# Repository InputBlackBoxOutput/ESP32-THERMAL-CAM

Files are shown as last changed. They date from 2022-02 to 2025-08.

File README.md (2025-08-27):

# ESP32 THERMAL CAM

## Assembly
- Enclosure consists of two parts and is held together using self-tapping screws 
- The PCB is attached to the enclosure using self-tapping screws driven into mounting bosses

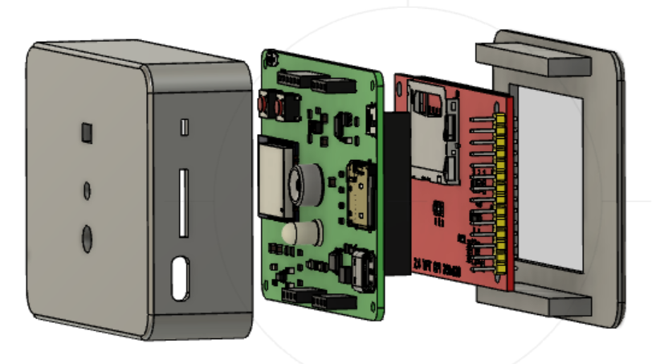
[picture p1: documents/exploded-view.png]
assembly


## Hardware block diagram
- ESP32-WROOM: Control the functionality of the entire design
- LEDs: Indicate the status of the thermal camera
- Pushbutton: Indicate the camera to save the image
- TFT Display: Display thermal images captured by the camera
- SD Card: Store thermal image captured by the camera
- TOF Proximity Sensor: Calculate the proximity of the camera with the surface in front of it
- IR Thermal Sensor Array: Capture IR emissions and create a thermal image of the surface
- LiPo Battery + BMS: Provide power to the camera thereby making it portable

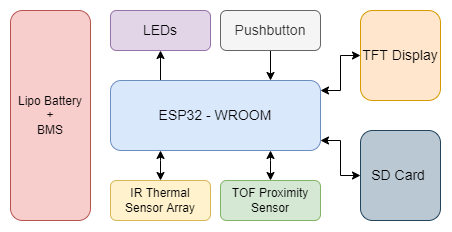
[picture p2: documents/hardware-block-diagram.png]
Hardware block diagram


## Application
- Connect with the thermal camera
- Display thermal image with an appropriate legend 
- Capture and save the thermal image 

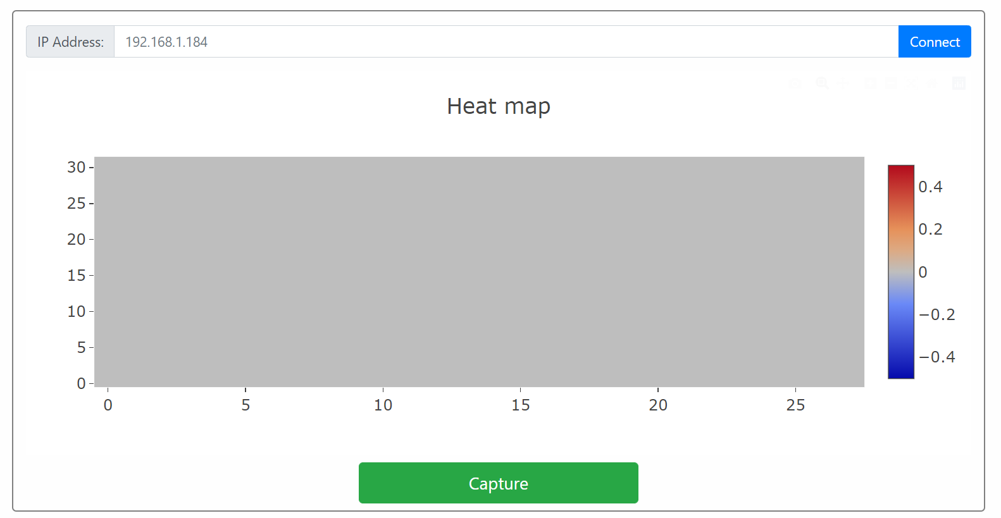
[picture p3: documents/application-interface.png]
Application interface


### Made with lots of ⏱️, 📚 and ☕ by InputBlackBoxOutput

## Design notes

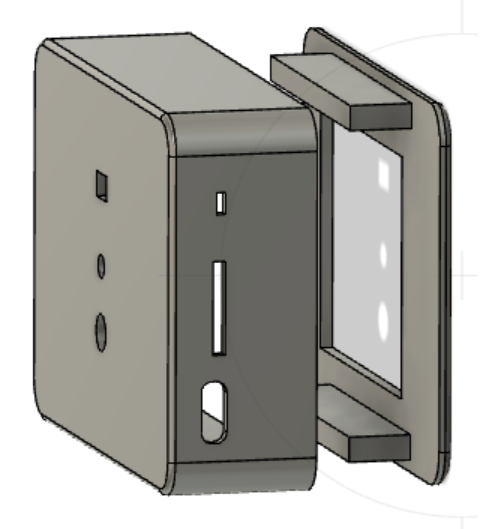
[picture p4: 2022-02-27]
enclosure/enclosure.png

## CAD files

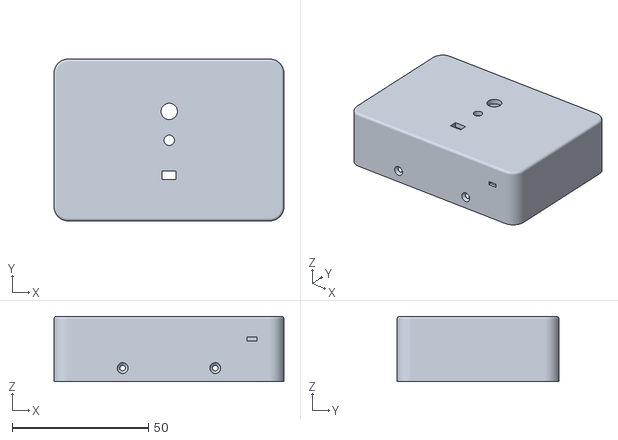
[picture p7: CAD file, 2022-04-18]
enclosure/Enclosure-Front.stl
84.4 x 59.4 x 24.0

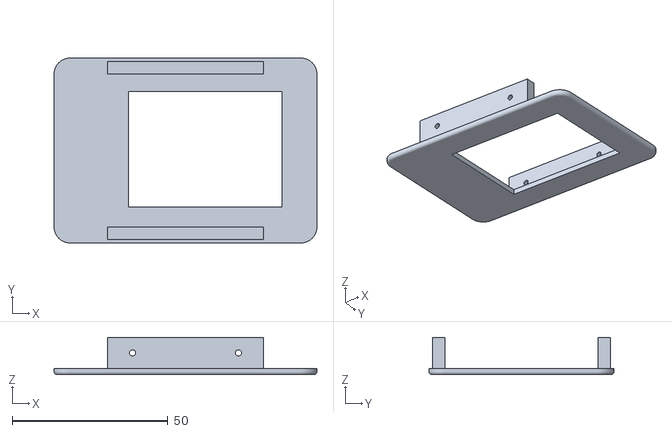
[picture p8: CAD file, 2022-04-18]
enclosure/Enclosure-Back-With-Display-Cutout.stl
84.4 x 59.4 x 12.0

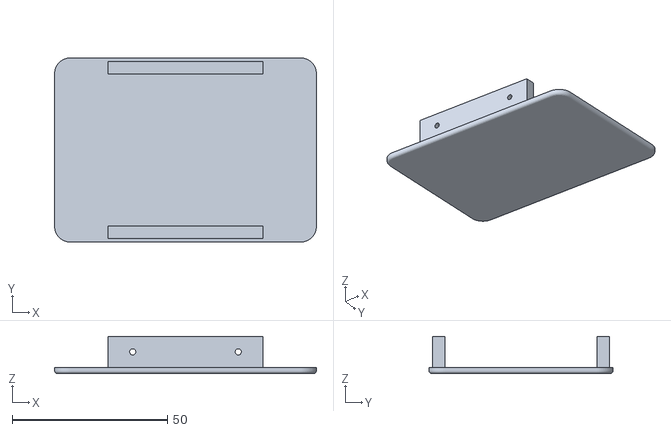
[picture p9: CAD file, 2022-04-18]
enclosure/Enclosure-Back-Without-Display-Cutout.stl
84.4 x 59.4 x 12.0

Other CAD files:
enclosure/Enclosure-Back-With-Display-Cutout.f3d
enclosure/Enclosure-Back-Without-Display-Cutout.f3d
enclosure/Enclosure-Front.f3d

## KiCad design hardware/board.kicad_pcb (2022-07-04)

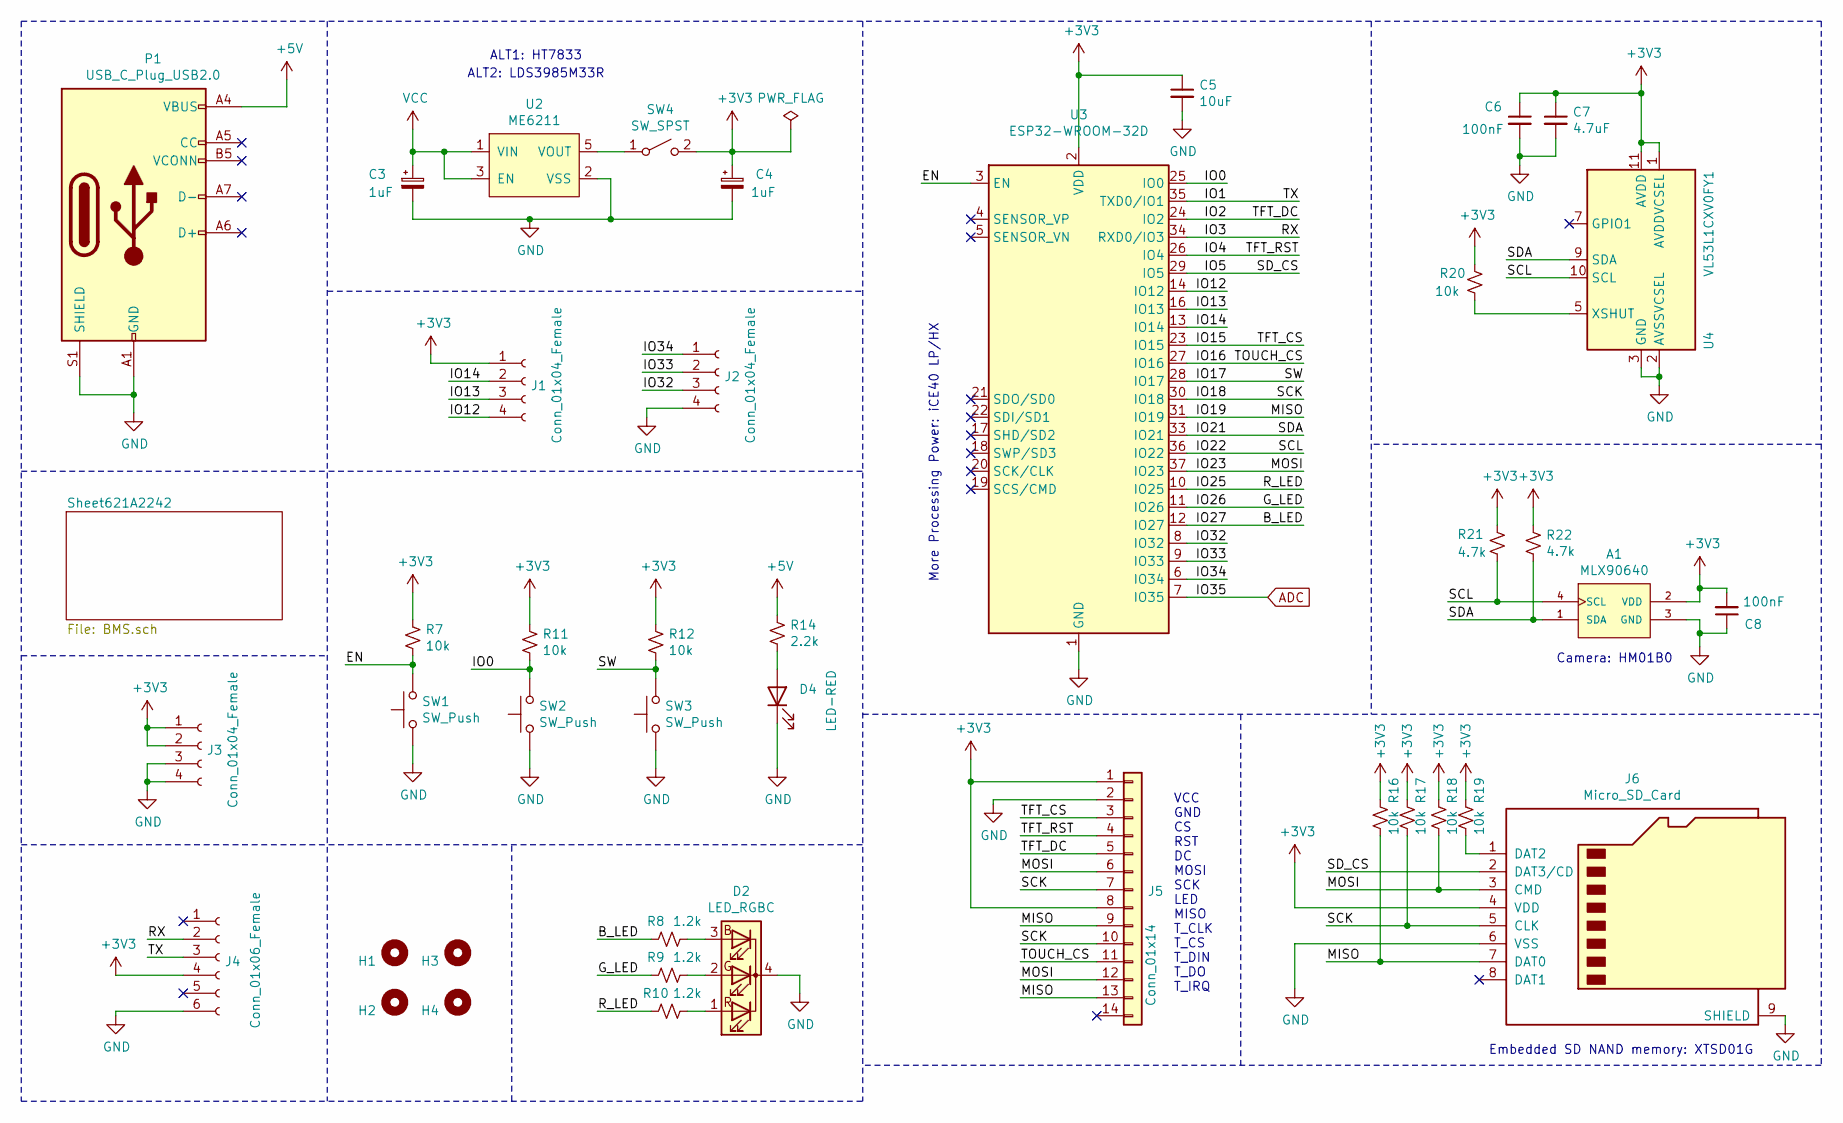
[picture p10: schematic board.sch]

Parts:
A1: MLX90640; TO292P930H600-4; PARTREV 11
C3, C4: 1uF; C_0805_2012Metric_Pad1.18x1.45mm_HandSolder
C5: 10uF; C_0805_2012Metric_Pad1.18x1.45mm_HandSolder
C6, C8: 100nF; C_0805_2012Metric_Pad1.18x1.45mm_HandSolder
C7: 4.7uF; C_0805_2012Metric_Pad1.18x1.45mm_HandSolder
D2: LED_RGBC; LED_D5.0mm-4_RGB
D4: LED-RED; LED_0805_2012Metric_Pad1.15x1.40mm_HandSolder
H1, H2, H3, H4: MountingHole; MountingHole_2.2mm_M2
J1, J2, J3: Conn_01x04_Female; PinSocket_1x04_P2.54mm_Vertical
J4: Conn_01x06_Female; PinSocket_1x06_P2.54mm_Vertical
J5: Conn_01x14; PinSocket_1x14_P2.54mm_Vertical_SMD_Pin1Left
J6: Micro_SD_Card; GCT-MEM2055-00-190-01-A
P1: USB_C_Plug_USB2.0; USB_C_Receptacle_HRO_TYPE-C-31-M-12
R7, R11, R12, R16, R17, R18, R19, R20: 10k; R_0805_2012Metric_Pad1.20x1.40mm_HandSolder
R8, R9, R10: 1.2k; R_0805_2012Metric_Pad1.20x1.40mm_HandSolder
R14: 2.2k; R_0805_2012Metric_Pad1.20x1.40mm_HandSolder
R21, R22: 4.7k; R_0805_2012Metric_Pad1.20x1.40mm_HandSolder
SW1, SW2: SW_Push; SW_SPST_Omron_B3FS-100xP
SW3: SW_Push; SW_SPST_EVQP7A
SW4: SW_SPST; SW_SPDT_PCM12
U2: ME6211; SOT-23-5_HandSoldering
U3: ESP32-WROOM-32D; ESP32-WROOM-32
U4: VL53L1CXV0FY1; ST_VL53L1x

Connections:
+3V3: A1.2 (VDD), C4.1, C5.1, C6.1, C7.1, C8.2, J1.1, J3.1, J3.2, J4.4, J5.1, J5.8, J6.4 (VDD), R7.1, R11.1, R12.1, R16.1, R17.1, R18.1, R19.1, R20.1, R21.1, R22.1, SW4.2 (B), U3.2 (VDD), U4.1 (AVDDVCSEL), U4.11 (AVDD)
+5V: P1.A4 (VBUS), P1.A9 (VBUS), P1.B4 (VBUS), P1.B9 (VBUS), R14.1; also elsewhere on the board
/B_LED: R8.2, U3.12 (IO27)
/EN: R7.2, SW1.2, U3.3 (EN)
/G_LED: R9.2, U3.11 (IO26)
/IO0: R11.2, SW2.2, U3.25 (IO0)
/IO1: J4.3, U3.35 (TXD0/IO1)
/IO2: J5.5, U3.24 (IO2)
/IO3: J4.2, U3.34 (RXD0/IO3)
/IO4: J5.4, U3.26 (IO4)
/IO5: J6.2 (DAT3/CD), U3.29 (IO5)
/IO12: J1.4, U3.14 (IO12)
/IO13: J1.3, U3.16 (IO13)
/IO14: J1.2, U3.13 (IO14)
/IO15: J5.3, U3.23 (IO15)
/IO16: J5.11, U3.27 (IO16)
/IO17: R12.2, SW3.2, U3.28 (IO17)
/IO18: J5.7, J5.10, J6.5 (CLK), R17.2, U3.30 (IO18)
/IO19: J5.9, J5.13, J6.7 (DAT0), R16.2, U3.31 (IO19)
/IO21: A1.1 (SDA), R22.2, U3.33 (IO21), U4.9 (SDA)
/IO22: A1.4 (SCL), R21.2, U3.36 (IO22), U4.10 (SCL)
/IO23: J5.6, J5.12, J6.3 (CMD), R18.2, U3.37 (IO23)
/IO25: R10.2, U3.10 (IO25)
/IO32: J2.3, U3.8 (IO32)
/IO33: J2.2, U3.9 (IO33)
/IO34: J2.1, U3.6 (IO34)
ADC: U3.7 (IO35); also elsewhere on the board
GND: A1.3 (GND), C3.2, C4.2, C5.2, C6.2, C7.2, C8.1, D2.4 (K), D4.1 (K), J2.4, J3.3, J3.4, J4.6, J5.2, J6.6 (VSS), J6.9 (SHIELD), P1.A1 (GND), P1.A12 (GND), P1.B1 (GND), P1.B12 (GND), P1.S1 (SHIELD), SW1.1, SW2.1, SW3.1, U2.2 (VSS), U3.1 (GND), U3.15 (GND), U3.38 (GND), U3.39 (GND), U4.2 (AVSSVCSEL), U4.3 (GND), U4.4 (GND), U4.6 (GND), U4.12 (GND); also elsewhere on the board
unnamed: D2.1 (RA), R10.1
unnamed: D2.2 (GA), R9.1
unnamed: D2.3 (BA), R8.1
unnamed: D4.2 (A), R14.2
unnamed: J6.1 (DAT2), R19.2
unnamed: R20.2, U4.5 (XSHUT)
unnamed: SW4.1 (A), U2.5 (VOUT)
VCC: C3.1, U2.1 (VIN), U2.3 (EN); also elsewhere on the board

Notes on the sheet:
Camera: HM01B0
More Processing Power: iCE40 LP/HX
VCC GND CS RST DC MOSI SCK LED MISO T_CLK T_CS T_DIN T_DO T_IRQ
Embedded SD NAND memory: XTSD01G
ALT1: HT7833
ALT2: LDS3985M33R

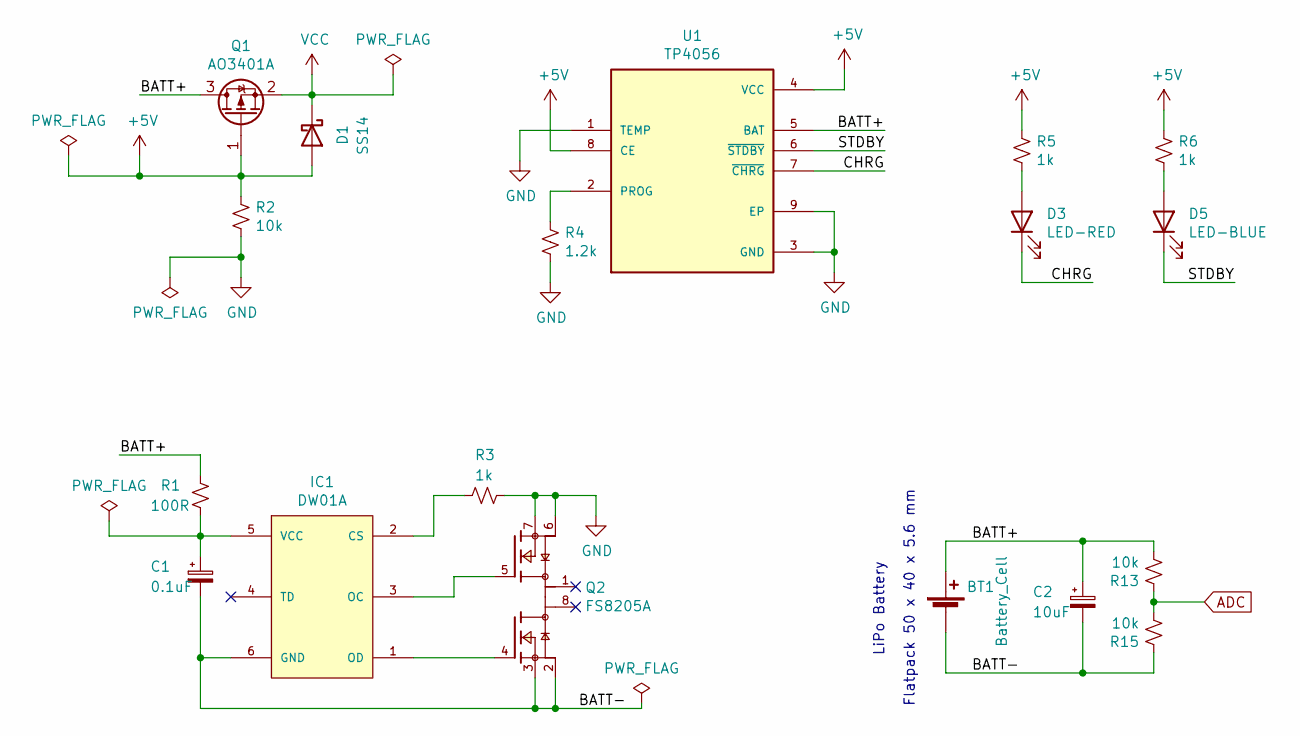
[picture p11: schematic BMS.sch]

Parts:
BT1: Battery_Cell; SolderWire-01x02-SMD-BATT
C1: 0.1uF; C_0805_2012Metric_Pad1.18x1.45mm_HandSolder
C2: 10uF; C_0805_2012Metric_Pad1.18x1.45mm_HandSolder
D1: SS14; D_SMB
D3: LED-RED; LED_0805_2012Metric_Pad1.15x1.40mm_HandSolder
D5: LED-BLUE; LED_0805_2012Metric_Pad1.15x1.40mm_HandSolder
IC1: DW01A; SOT-23-6_Handsoldering; MPN DW01A; LCSC C351410
Q1: AO3401A; SOT-23
Q2: FS8205A; SOP65P640X120-8N; PARTREV 1.7
R1: 100R; R_0805_2012Metric_Pad1.20x1.40mm_HandSolder
R2, R13, R15: 10k; R_0805_2012Metric_Pad1.20x1.40mm_HandSolder
R3, R5, R6: 1k; R_0805_2012Metric_Pad1.20x1.40mm_HandSolder
R4: 1.2k; R_0805_2012Metric_Pad1.20x1.40mm_HandSolder
U1: TP4056; SOP127P600X175-9N

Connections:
+5V: D1.2 (A), Q1.1 (G), R2.1, R5.1, R6.1, U1.4 (VCC), U1.8 (CE); also elsewhere on the board
/Sheet621A2242/BATT+: BT1.1 (+), C2.1, Q1.3 (D), R1.1, R13.2, U1.5 (BAT)
/Sheet621A2242/BATT-: BT1.2 (-), C1.2, C2.2, IC1.6 (GND), Q2.2, Q2.3, R15.1
/Sheet621A2242/CHRG: D3.1 (K), U1.7 (~CHRG)
/Sheet621A2242/STDBY: D5.1 (K), U1.6 (~STDBY)
ADC: R13.1, R15.2; also elsewhere on the board
GND: Q2.6, Q2.7, R2.2, R3.1, R4.2, U1.1 (TEMP), U1.3 (GND), U1.9 (EP); also elsewhere on the board
unnamed: C1.1, IC1.5 (VCC), R1.2
unnamed: D3.2 (A), R5.2
unnamed: D5.2 (A), R6.2
unnamed: IC1.1 (OD), Q2.4
unnamed: IC1.2 (CS), R3.2
unnamed: IC1.3 (OC), Q2.5
unnamed: R4.1, U1.2 (PROG)
VCC: D1.1 (K), Q1.2 (S); also elsewhere on the board

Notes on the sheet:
LiPo Battery
Flatpack 50 x 40 x 5.6 mm

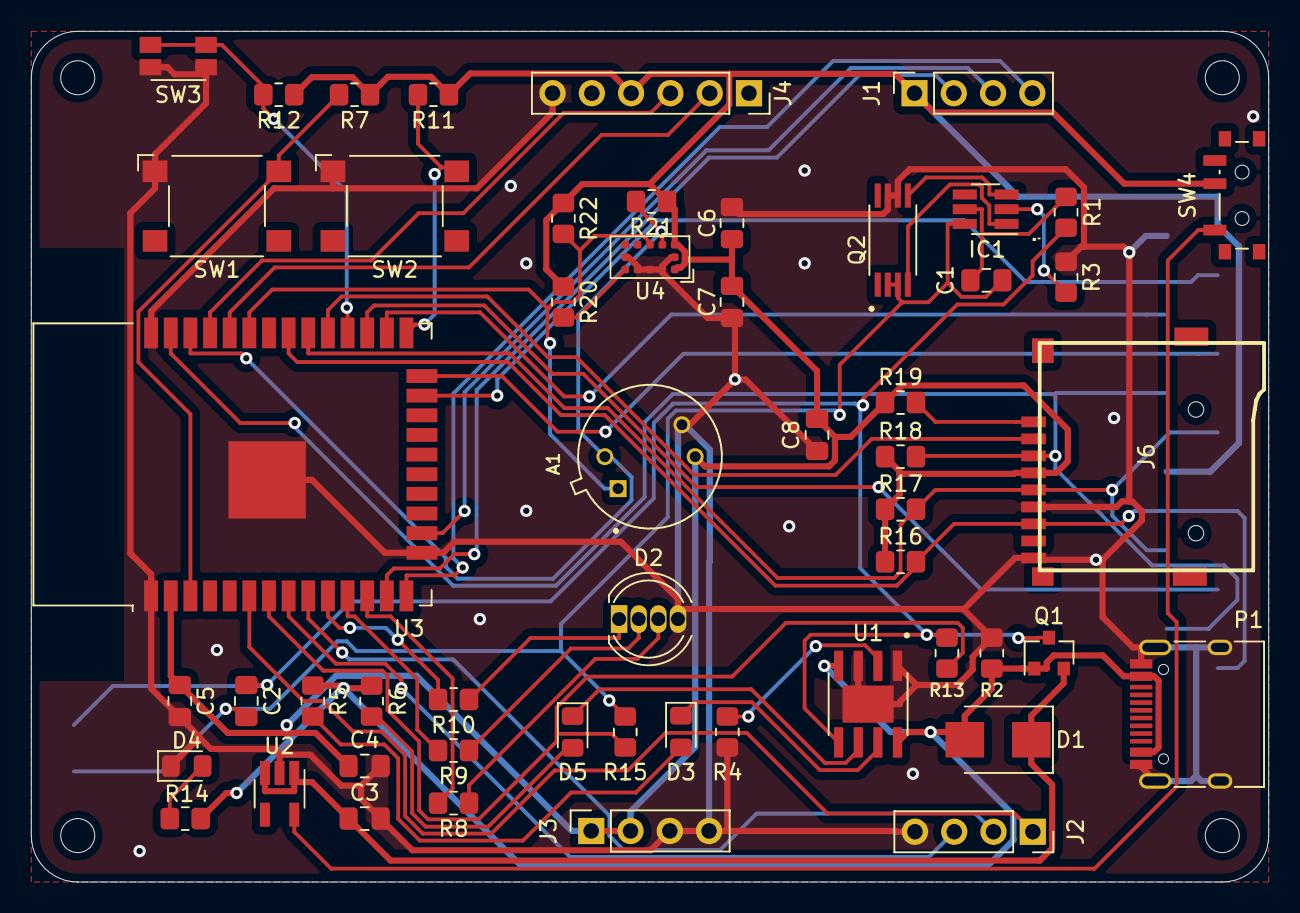
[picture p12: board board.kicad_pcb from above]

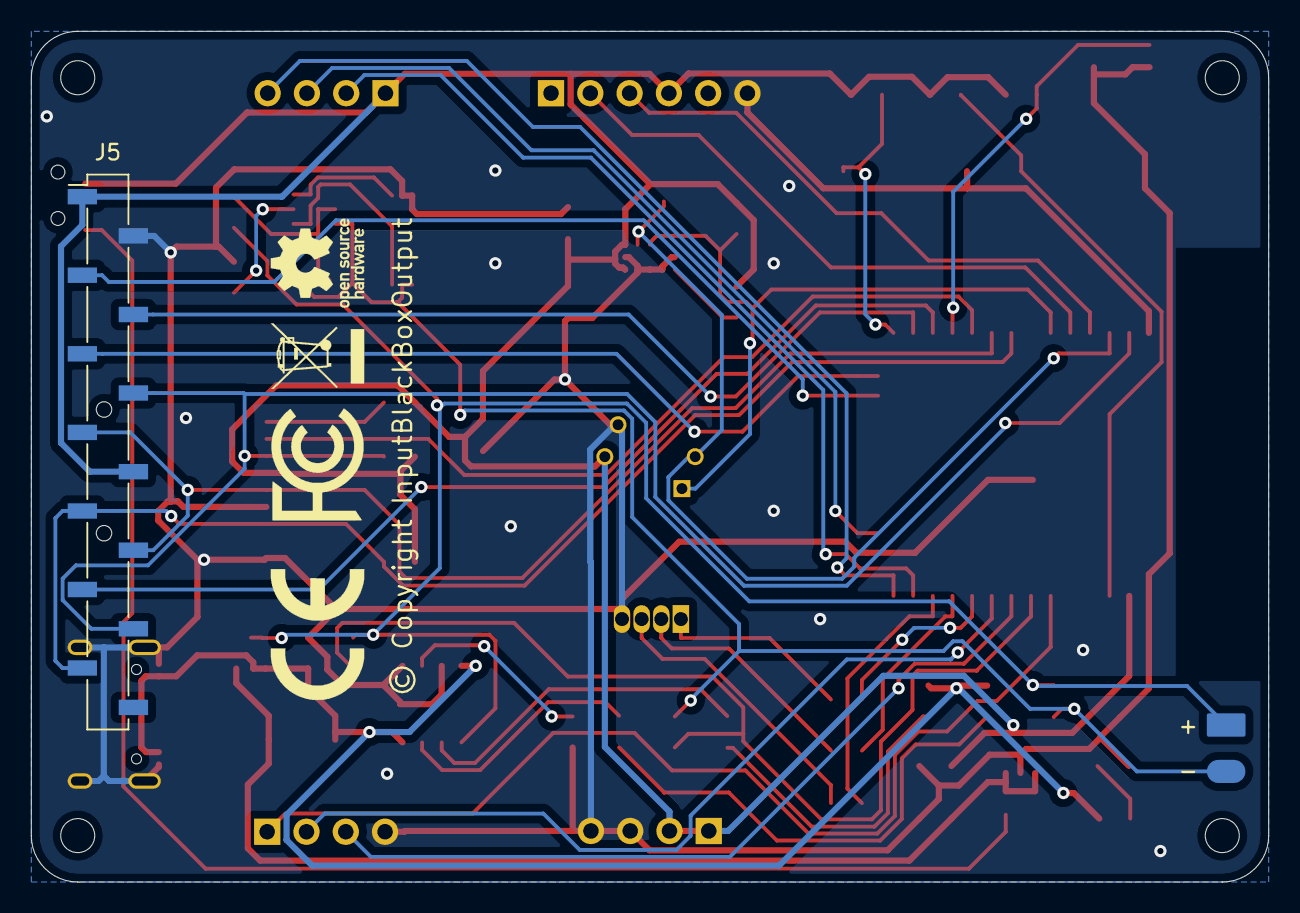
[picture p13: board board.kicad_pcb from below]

Board: 2 copper layers, 80.0 x 55.0 mm, 59 parts (2 on the bottom side), 47 nets.

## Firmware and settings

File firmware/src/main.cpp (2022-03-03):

#include <Arduino.h>
#define LOOP_DELAY 200 // ms

#include "MLX90640.h"
#include "server.h"

MLX90640 mlx;
ESP32Server server;

void setup()
{
  Serial.begin(115200);
  Serial.println("Serial port connected!");

  mlx.setup();
  server.setup();
}

void loop()
{
  mlx.readTempValues();
  server.handleClient(mlx.timestamp, mlx.tempValues);

  delay(LOOP_DELAY);
}

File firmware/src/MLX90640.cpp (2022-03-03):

#include "MLX90640.h"

void MLX90640::setup()
{
    // Connect with MLX90640 via I2C
    Wire.begin();
    Wire.setClock(400000);
    Wire.beginTransmission((uint8_t)MLX90640_address);
    if (Wire.endTransmission() != 0)
        Serial.println("MLX90640 not detected at default I2C address. Please check wiring.");
    else
        Serial.println("MLX90640 initialized!");

    // Get MLX90640 device parameters
    int status;
    uint16_t eeMLX90640[832];

    status = MLX90640_DumpEE(MLX90640_address, eeMLX90640);
    if (status != 0)
        Serial.println("Failed to load system parameters");

    status = MLX90640_ExtractParameters(eeMLX90640, &mlx90640);
    if (status != 0)
        Serial.println("Parameter extraction failed");

    MLX90640_SetRefreshRate(MLX90640_address, 0x05); // 8Hz
    Wire.setClock(800000);
}

// Read pixel data from MLX90640.
void MLX90640::readTempValues()
{
    timestamp = millis();
    for (byte x = 0; x < 2; x++) // Read both subpages
    {
        uint16_t mlx90640Frame[834];
        int status = MLX90640_GetFrameData(MLX90640_address, mlx90640Frame);
        if (status < 0)
        {
            Serial.print("GetFrame Error: ");
            Serial.println(status);
        }

        // float vdd = MLX90640_GetVdd(mlx90640Frame, &mlx90640);
        float Ta = MLX90640_GetTa(mlx90640Frame, &mlx90640);

        float tr = Ta - ta_shift; // Reflected temperature based on the sensor ambient temperature

        MLX90640_CalculateTo(mlx90640Frame, &mlx90640, emmisivity, tr, tempValues);
    }
}

void MLX90640::printTempValues()
{
    Serial.print("Timestamp: ");
    Serial.println(timestamp);

    for (int i = 0; i < 768; i++)
    {
        Serial.print(tempValues[i]);
        if (i != 767)
            Serial.print(",");
    }
    Serial.println();
}

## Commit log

2022-02-27 Hardware added
    [BMS.sch, board.dsn, board.kicad_pcb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]
2022-02-27 Enclosure added
    [enclosure_part1.f3d, enclosure_part1.stl, enclosure_part2.f3d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]
2022-03-02 Silkscreen markings added + Minor changes to tracks
    [board.kicad_pcb]
2022-03-10 Minor changes to the PCB
    [board.kicad_pcb]
2022-04-18 Enclosure lid variants added
    [Enclosure-Back-With-Display-Cutout.f3d, Enclosure-Back-With-Display-Cutout.stl, Enclosure-Back-Without-Display-Cutout.f3d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]
2022-05-05 CE, FCC, WEEE and OSHW markings added to PCB
    [board.kicad_pcb]
2022-07-04 Folder reorganized: hardware
    [board.kicad_pcb, board.sch]

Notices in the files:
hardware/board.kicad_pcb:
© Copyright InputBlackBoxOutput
